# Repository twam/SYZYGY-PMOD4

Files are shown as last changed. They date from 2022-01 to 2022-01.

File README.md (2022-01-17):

SYZYGY-PMOD4
===

Board for adapting a [SYZYGY](https://syzygyfpga.io) Standard compatible port to four [Pmod™](https://digilent.com/reference/pmod/) compatible ports.
It is based on [SZG-PMOD4](https://opalkelly.com/products/szg-pmod4/) by [Opal Kelly](https://opalkelly.com).

### Images

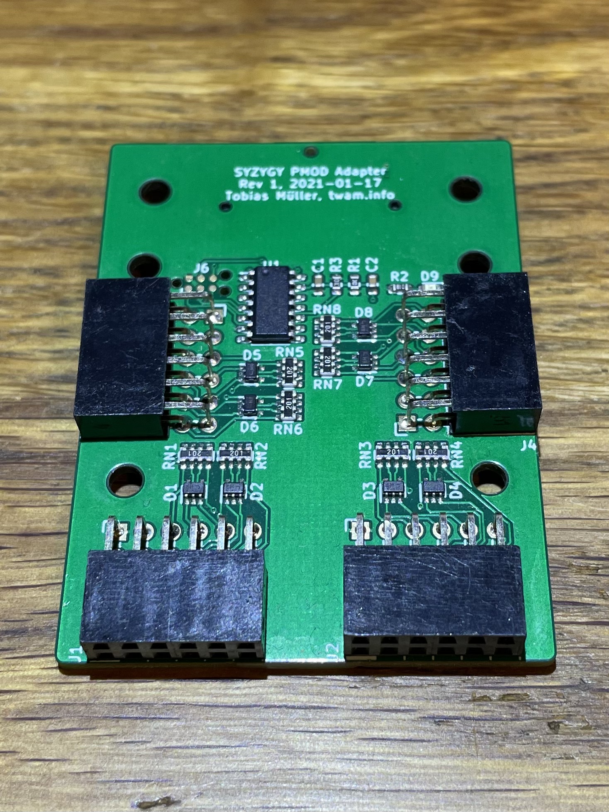
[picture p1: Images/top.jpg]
Top

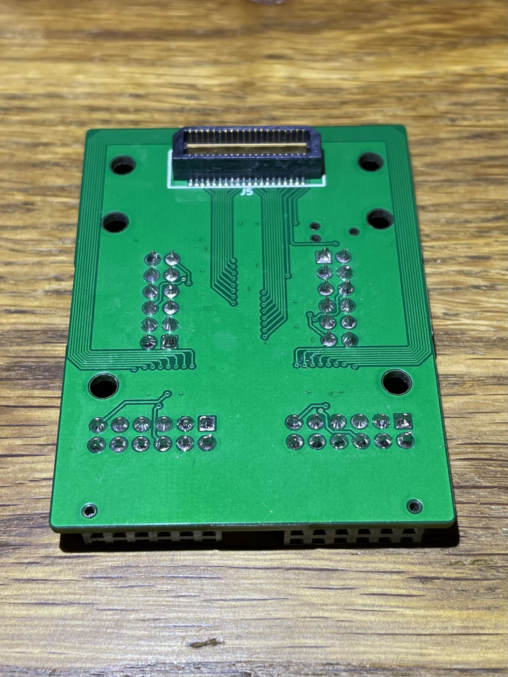
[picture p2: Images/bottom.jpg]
Bottom


### Firmware

The board is compatible with the [avr-dna-fw](https://github.com/SYZYGYfpga/avr-dna-fw) reference firmware.

### JLCPCB

PCBs can be ordered fully-assembled (besides the High-Speed connector on the bottom side and the pin headers) from [JLCPCB](https://jlcpcb.com/DDE). Required files are
[SYZYGY-PMOD4_bom_jlc.csv](Gerber/SYZYGY-PMOD4_bom_jlc.csv), [SYZYGY-PMOD4_cpl_jlc.csv](Gerber/SYZYGY-PMOD4_cpl_jlc.csv) and
[SYZYGY-PMOD4.zip](SYZYGY-PMOD4.zip).

## License

[][cc-by-sa]

This work is licensed under a [Creative Commons Attribution-NonCommercial-ShareAlike 4.0 International License][cc-by-sa].

[][cc-by-sa]

[cc-by-sa]: http://creativecommons.org/licenses/by-nc-sa/4.0/
[cc-by-sa-image]: https://licensebuttons.net/l/by-nc-sa/4.0/88x31.png
[cc-by-sa-shield]: https://img.shields.io/badge/License-CC%20BY--NC--SA%204.0-lightgrey.svg

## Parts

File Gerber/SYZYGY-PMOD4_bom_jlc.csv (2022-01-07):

Comment | Designator | Footprint | LCSC Part #
100n | C2,C1 | C_0603_1608Metric | C14663
NSQA6V8AW5T2G | D2,D3,D4,D5,D6,D7,D8,D1 | SOT-353_SC-70-5 | C233419
green | D9 | LED_0603_1608Metric | C72043
10k | R1,R3 | R_0603_1608Metric | C25804
1k | R2 | R_0603_1608Metric | C21190
200R | RN1,RN2,RN3,RN4,RN5,RN6,RN7,RN8 | R_Array_Convex_4x0603 | C29486
ATtiny44-20SS | U1 | SOIC-14_3.9x8.7mm_P1.27mm | C23640

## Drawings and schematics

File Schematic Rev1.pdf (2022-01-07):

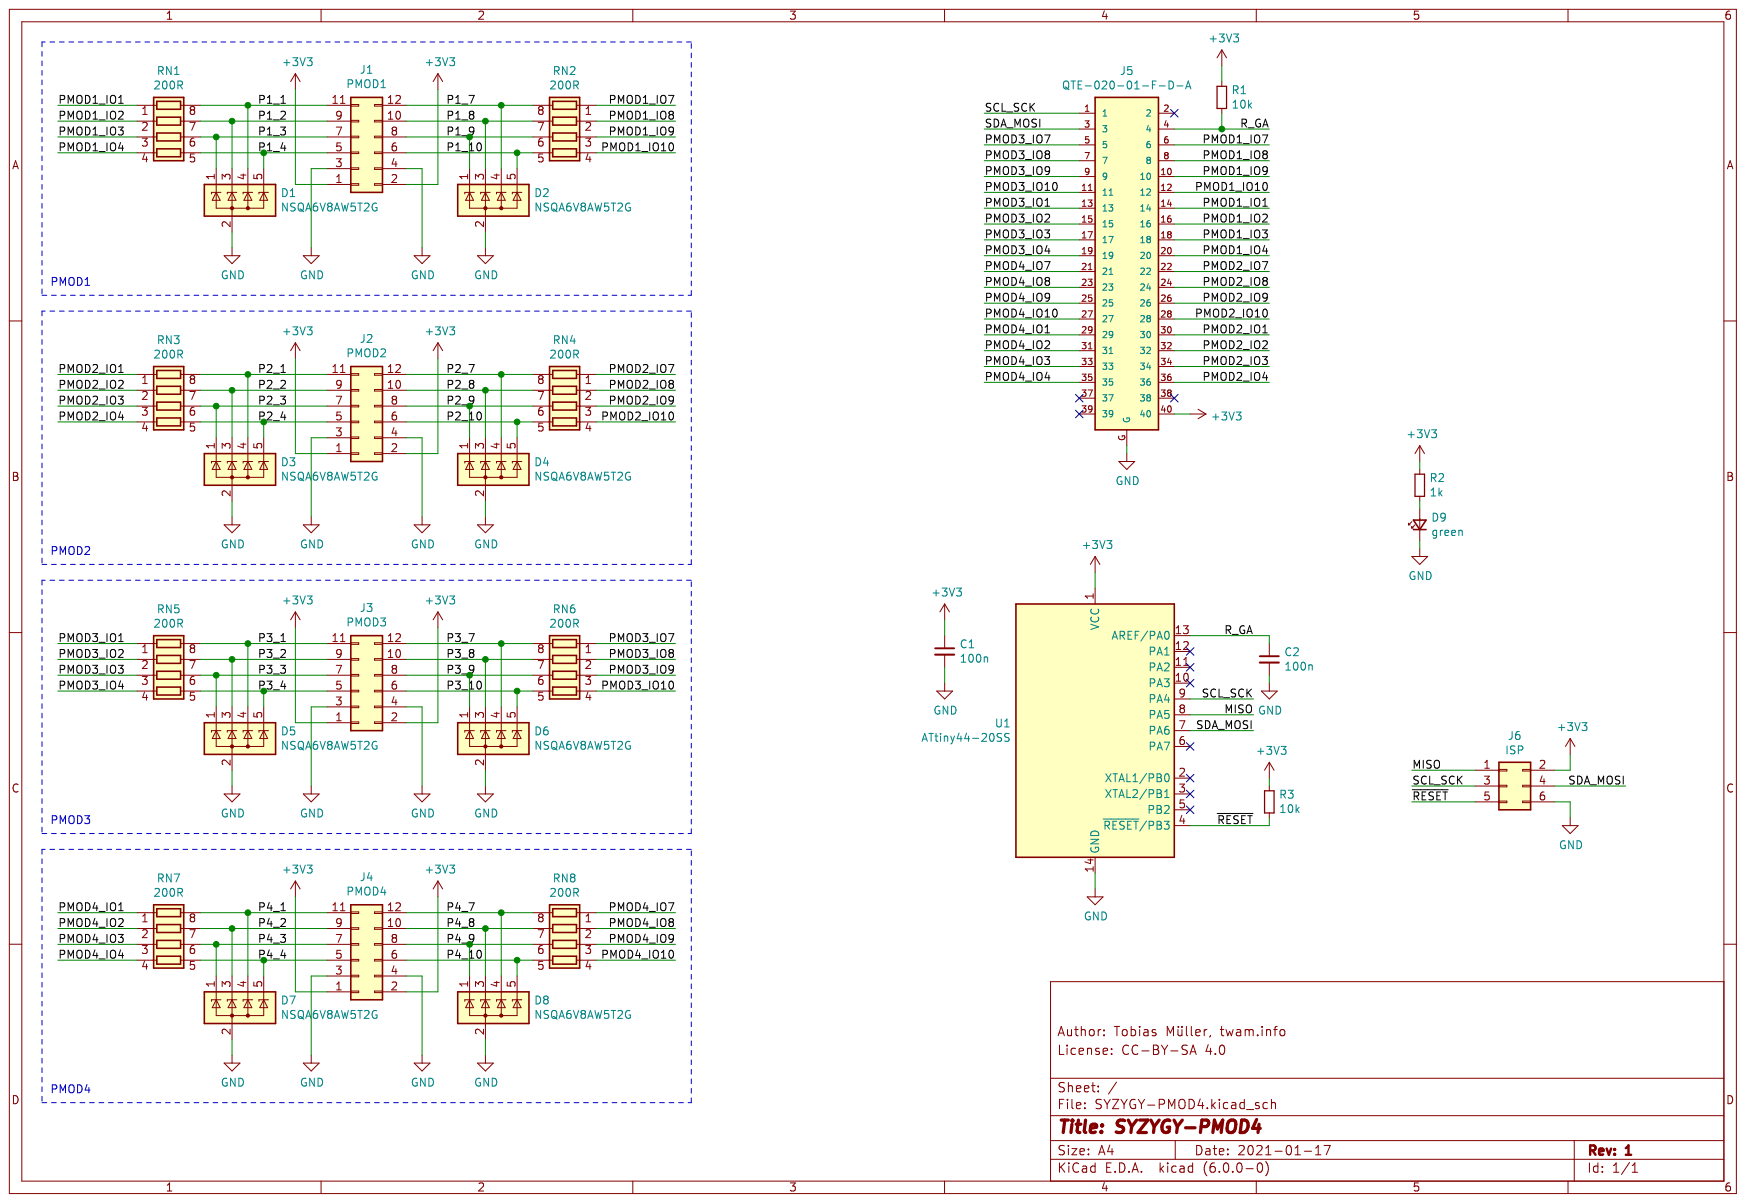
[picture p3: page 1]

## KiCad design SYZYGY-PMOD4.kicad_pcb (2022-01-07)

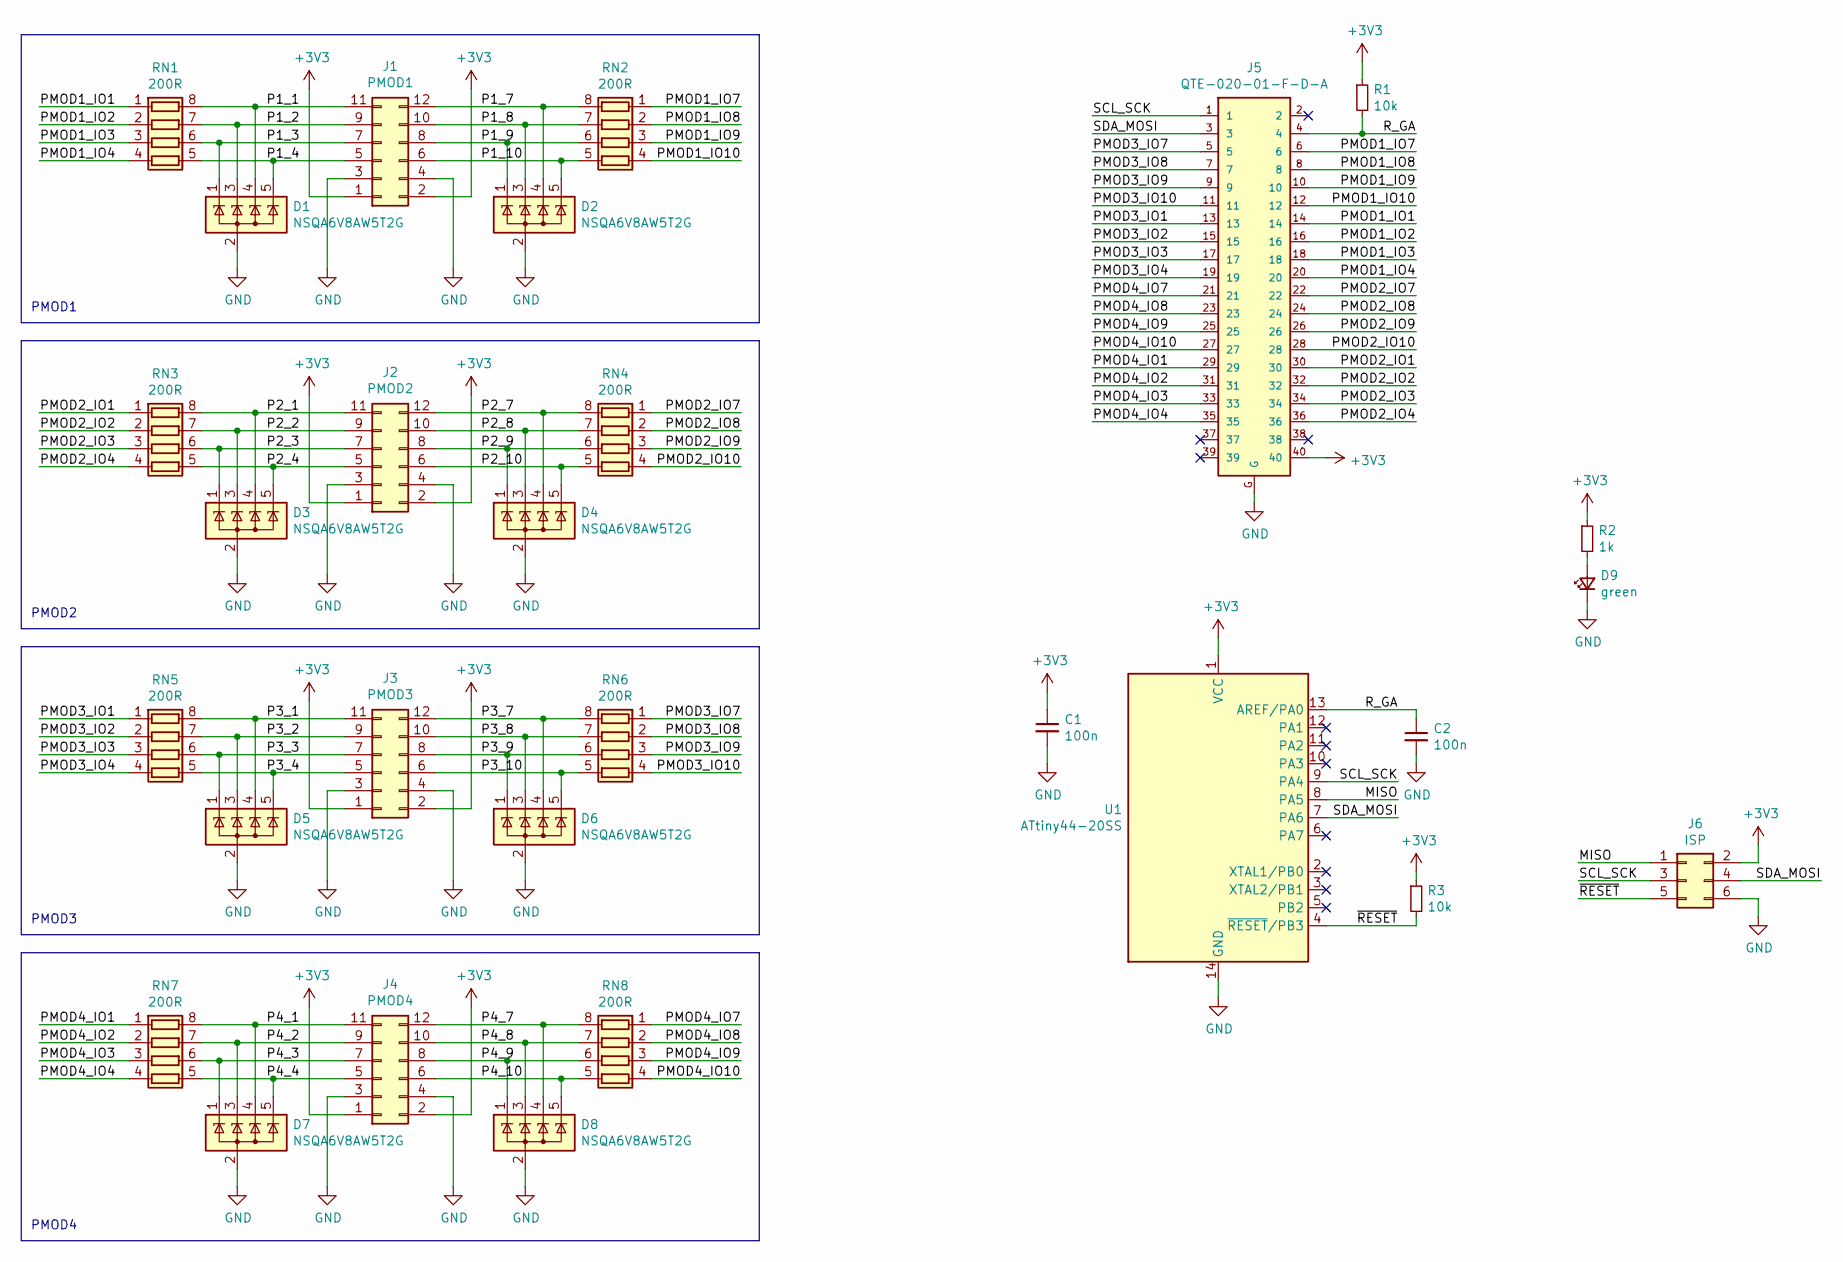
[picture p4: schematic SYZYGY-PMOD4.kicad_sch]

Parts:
C1, C2: 100n; C_0603_1608Metric; LCSC C14663
D1, D2, D3, D4, D5, D6, D7, D8: NSQA6V8AW5T2G; SOT-353_SC-70-5; LCSC C233419
D9: green; LED_0603_1608Metric; LCSC C72043
J1: PMOD1; PinSocket_2x06_P2.54mm_Horizontal
J2: PMOD2; PinSocket_2x06_P2.54mm_Horizontal
J3: PMOD3; PinSocket_2x06_P2.54mm_Horizontal
J4: PMOD4; PinSocket_2x06_P2.54mm_Horizontal
J5: QTE-020-01-F-D-A
J6: ISP; Tag-Connect_TC2030-IDC-NL_2x03_P1.27mm_Vertical
R1, R3: 10k; R_0603_1608Metric; LCSC C25804
R2: 1k; R_0603_1608Metric; LCSC C21190
RN1, RN2, RN3, RN4, RN5, RN6, RN7, RN8: 200R; R_Array_Convex_4x0603; LCSC C29486
U1: ATtiny44-20SS; SOIC-14_3.9x8.7mm_P1.27mm; LCSC C23640

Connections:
+3V3: C1.1, J1.1, J1.2, J2.1, J2.2, J3.1, J3.2, J4.1, J4.2, J5.40, J6.2, R1.1, R2.1, R3.1, U1.1 (VCC)
/MISO: J6.1, U1.8 (PA5)
/P1_1: D1.4 (K), J1.11, RN1.8 (R1.2)
/P1_2: D1.3 (K), J1.9, RN1.7 (R2.2)
/P1_3: D1.1 (K), J1.7, RN1.6 (R3.2)
/P1_4: D1.5 (K), J1.5, RN1.5 (R4.2)
/P1_7: D2.4 (K), J1.12, RN2.8 (R1.2)
/P1_8: D2.3 (K), J1.10, RN2.7 (R2.2)
/P1_9: D2.1 (K), J1.8, RN2.6 (R3.2)
/P1_10: D2.5 (K), J1.6, RN2.5 (R4.2)
/P2_1: D3.4 (K), J2.11, RN3.8 (R1.2)
/P2_2: D3.3 (K), J2.9, RN3.7 (R2.2)
/P2_3: D3.1 (K), J2.7, RN3.6 (R3.2)
/P2_4: D3.5 (K), J2.5, RN3.5 (R4.2)
/P2_7: D4.4 (K), J2.12, RN4.8 (R1.2)
/P2_8: D4.3 (K), J2.10, RN4.7 (R2.2)
/P2_9: D4.1 (K), J2.8, RN4.6 (R3.2)
/P2_10: D4.5 (K), J2.6, RN4.5 (R4.2)
/P3_1: D5.4 (K), J3.11, RN5.8 (R1.2)
/P3_2: D5.3 (K), J3.9, RN5.7 (R2.2)
/P3_3: D5.1 (K), J3.7, RN5.6 (R3.2)
/P3_4: D5.5 (K), J3.5, RN5.5 (R4.2)
/P3_7: D6.4 (K), J3.12, RN6.8 (R1.2)
/P3_8: D6.3 (K), J3.10, RN6.7 (R2.2)
/P3_9: D6.1 (K), J3.8, RN6.6 (R3.2)
/P3_10: D6.5 (K), J3.6, RN6.5 (R4.2)
/P4_1: D7.4 (K), J4.11, RN7.8 (R1.2)
/P4_2: D7.3 (K), J4.9, RN7.7 (R2.2)
/P4_3: D7.1 (K), J4.7, RN7.6 (R3.2)
/P4_4: D7.5 (K), J4.5, RN7.5 (R4.2)
/P4_7: D8.4 (K), J4.12, RN8.8 (R1.2)
/P4_8: D8.3 (K), J4.10, RN8.7 (R2.2)
/P4_9: D8.1 (K), J4.8, RN8.6 (R3.2)
/P4_10: D8.5 (K), J4.6, RN8.5 (R4.2)
/PMOD1_IO1: J5.14, RN1.1 (R1.1)
/PMOD1_IO2: J5.16, RN1.2 (R2.1)
/PMOD1_IO3: J5.18, RN1.3 (R3.1)
/PMOD1_IO4: J5.20, RN1.4 (R4.1)
/PMOD1_IO7: J5.6, RN2.1 (R1.1)
/PMOD1_IO8: J5.8, RN2.2 (R2.1)
/PMOD1_IO9: J5.10, RN2.3 (R3.1)
/PMOD1_IO10: J5.12, RN2.4 (R4.1)
/PMOD2_IO1: J5.30, RN3.1 (R1.1)
/PMOD2_IO2: J5.32, RN3.2 (R2.1)
/PMOD2_IO3: J5.34, RN3.3 (R3.1)
/PMOD2_IO4: J5.36, RN3.4 (R4.1)
/PMOD2_IO7: J5.22, RN4.1 (R1.1)
/PMOD2_IO8: J5.24, RN4.2 (R2.1)
/PMOD2_IO9: J5.26, RN4.3 (R3.1)
/PMOD2_IO10: J5.28, RN4.4 (R4.1)
/PMOD3_IO1: J5.13, RN5.1 (R1.1)
/PMOD3_IO2: J5.15, RN5.2 (R2.1)
/PMOD3_IO3: J5.17, RN5.3 (R3.1)
/PMOD3_IO4: J5.19, RN5.4 (R4.1)
/PMOD3_IO7: J5.5, RN6.1 (R1.1)
/PMOD3_IO8: J5.7, RN6.2 (R2.1)
/PMOD3_IO9: J5.9, RN6.3 (R3.1)
/PMOD3_IO10: J5.11, RN6.4 (R4.1)
/PMOD4_IO1: J5.29, RN7.1 (R1.1)
/PMOD4_IO2: J5.31, RN7.2 (R2.1)
/PMOD4_IO3: J5.33, RN7.3 (R3.1)
/PMOD4_IO4: J5.35, RN7.4 (R4.1)
/PMOD4_IO7: J5.21, RN8.1 (R1.1)
/PMOD4_IO8: J5.23, RN8.2 (R2.1)
/PMOD4_IO9: J5.25, RN8.3 (R3.1)
/PMOD4_IO10: J5.27, RN8.4 (R4.1)
/R_GA: C2.1, J5.4, R1.2, U1.13 (AREF/PA0)
/SCL_SCK: J5.1, J6.3, U1.9 (PA4)
/SDA_MOSI: J5.3, J6.4, U1.7 (PA6)
/~RESET: J6.5, R3.2, U1.4 (~RESET/PB3)
GND: C1.2, C2.2, D1.2 (A), D2.2 (A), D3.2 (A), D4.2 (A), D5.2 (A), D6.2 (A), D7.2 (A), D8.2 (A), D9.1 (K), J1.3, J1.4, J2.3, J2.4, J3.3, J3.4, J4.3, J4.4, J5.G, J6.6, U1.14 (GND)
unnamed: D9.2 (A), R2.2

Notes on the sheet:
PMOD3
PMOD1
PMOD4
PMOD2

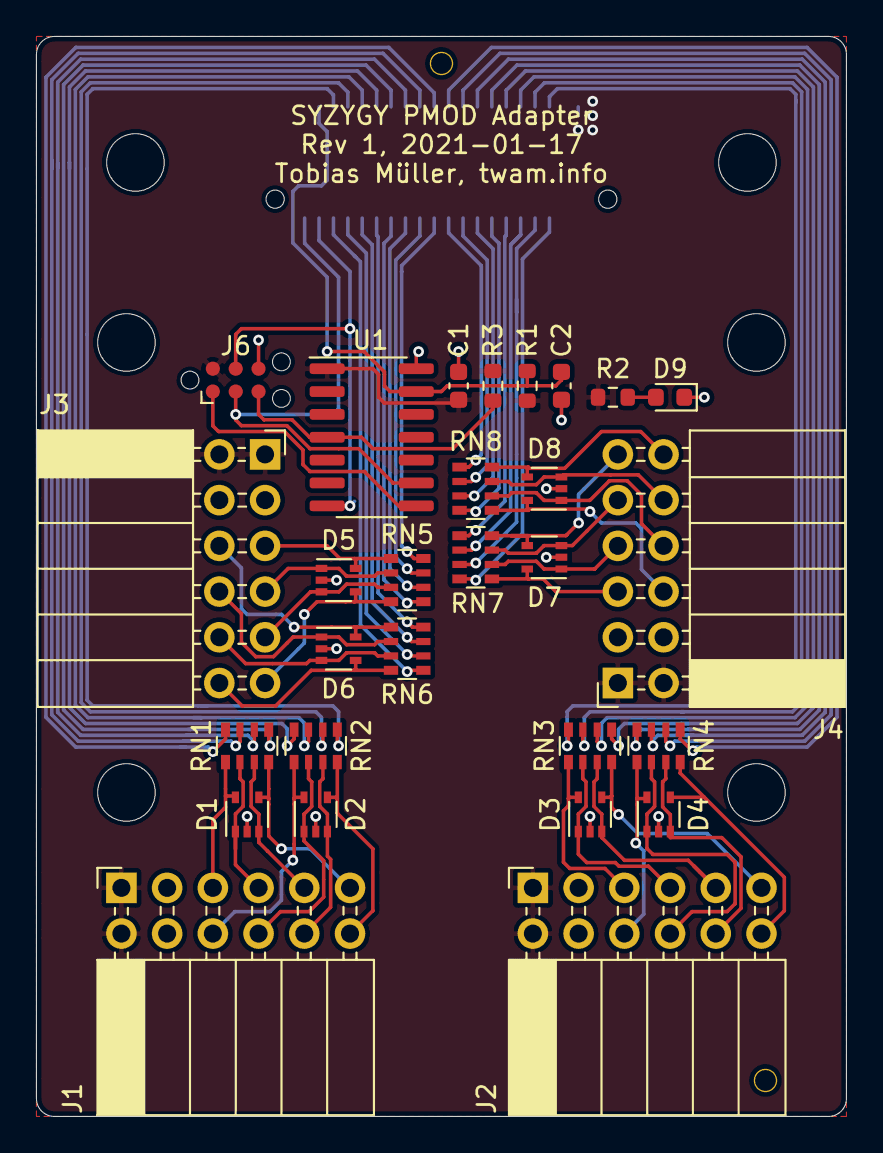
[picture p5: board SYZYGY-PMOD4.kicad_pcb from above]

Board: 2 copper layers, 45.0 x 60.0 mm, 29 parts (1 on the bottom side), 72 nets.

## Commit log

2022-01-07 Initial commit. Rev1.
    [SYZYGY-PMOD4-B_Cu.gbr, SYZYGY-PMOD4-B_Mask.gbr, SYZYGY-PMOD4-B_Paste.gbr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]
2022-01-07 Add schematic Rev1
2022-01-07 Update to KiCad 6
    [SYZYGY-PMOD4.kicad_pcb, SYZYGY-PMOD4.kicad_sch, SYZYGY-PMOD4.sch]

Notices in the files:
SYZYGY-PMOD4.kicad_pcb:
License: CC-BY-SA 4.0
